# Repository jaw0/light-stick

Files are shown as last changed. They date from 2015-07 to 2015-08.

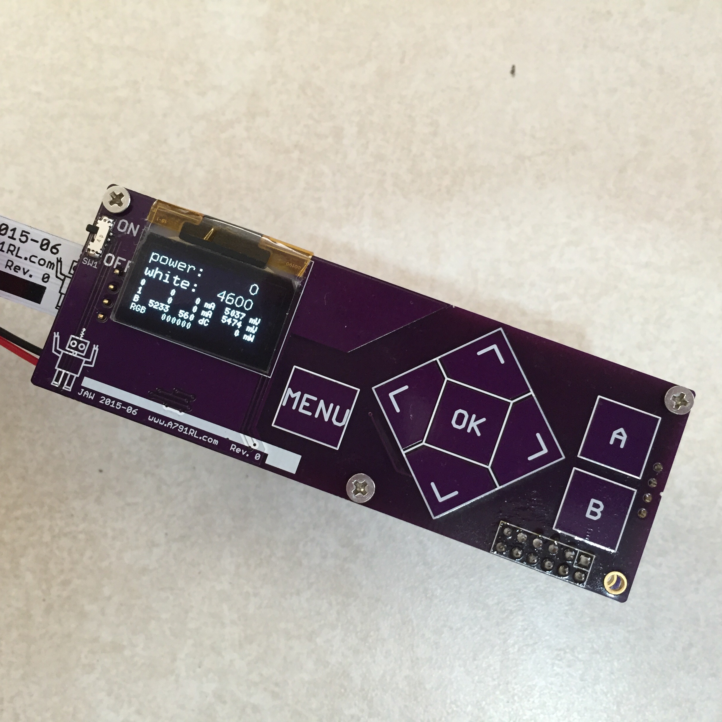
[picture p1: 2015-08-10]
img/userinterface.jpg

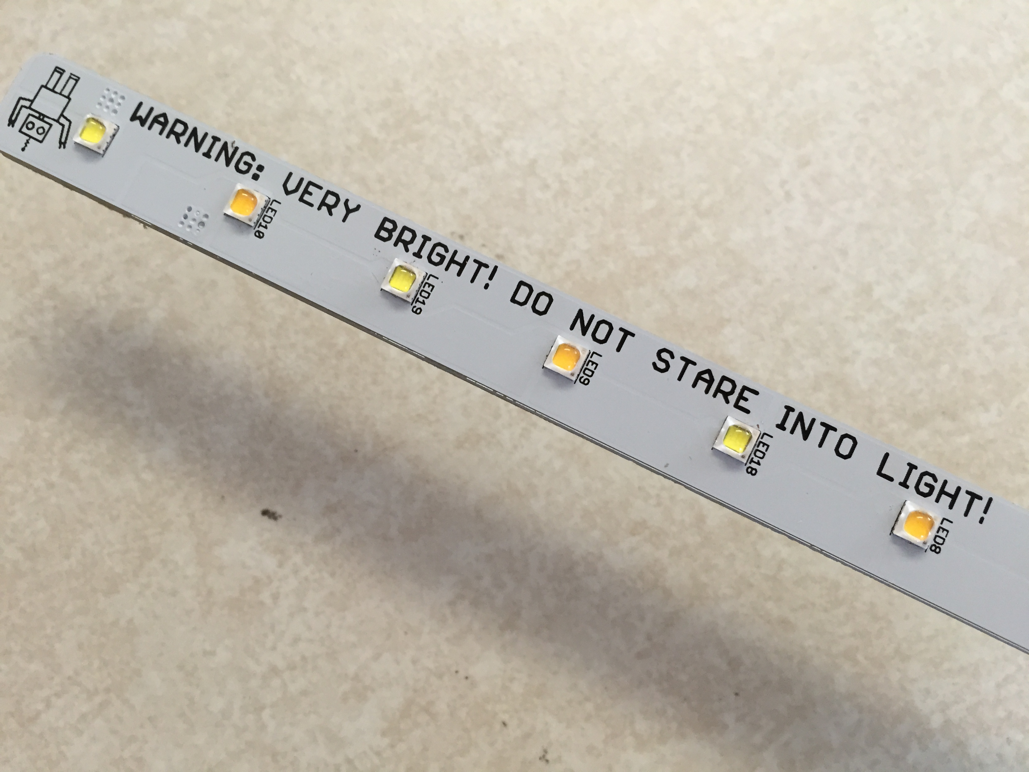
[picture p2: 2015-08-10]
img/leds.jpg

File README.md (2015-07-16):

LED based, battery powered light for photography + videography
modeled after Wescott's "Ice Light"

* aprox 4300 lumens

* 38 Watts

* adjustable power level

* adjustable color temperature: 2700K - 6500K

* consistent + stable output + color even as batteries die

* flicker free

* remembers settings when turned off

* OLED display + touch panel user interface

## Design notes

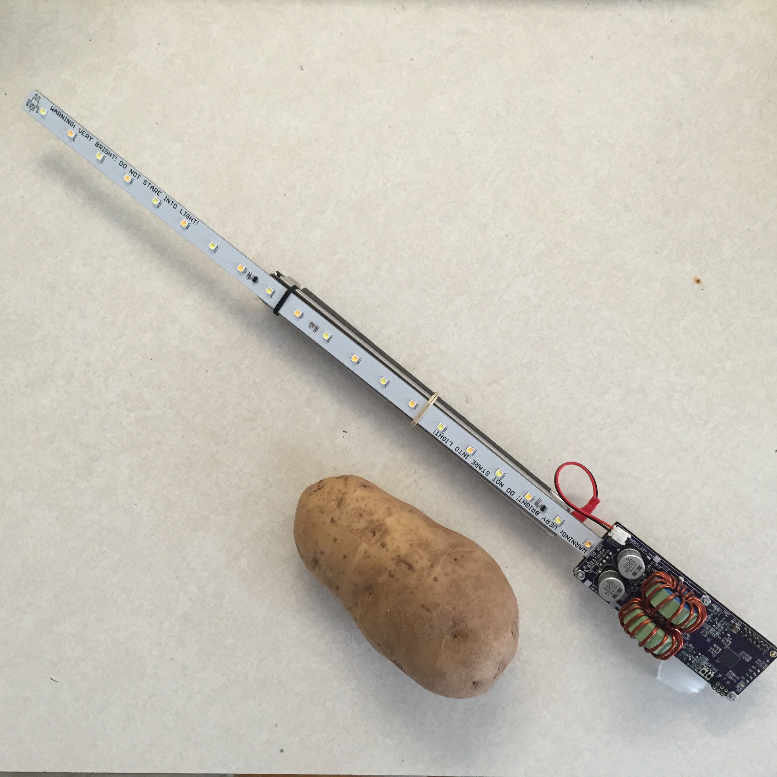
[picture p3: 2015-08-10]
img/potato-for-scale.jpg

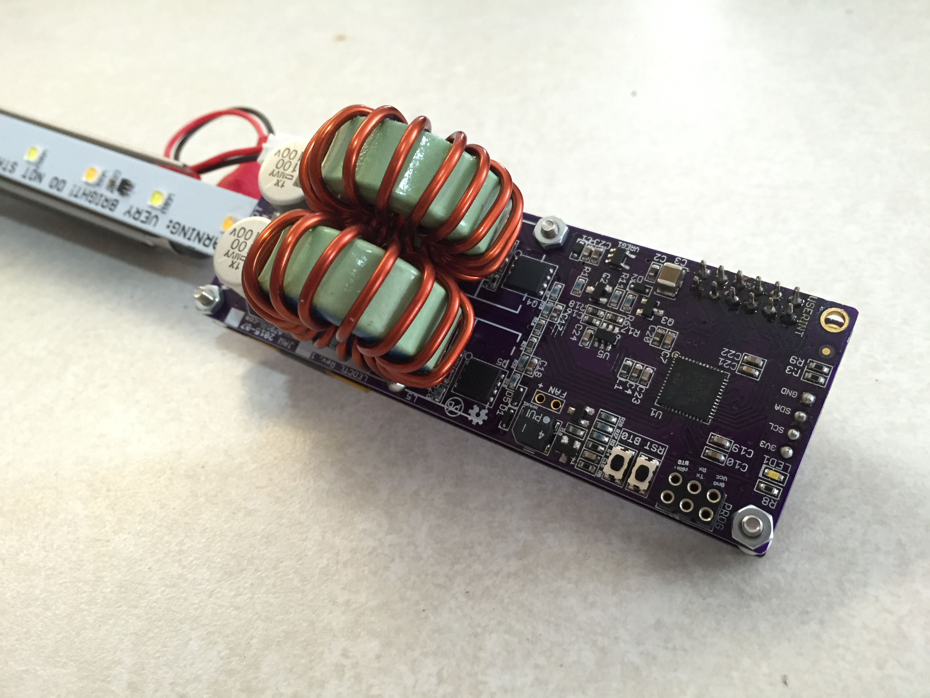
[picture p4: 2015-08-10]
img/mainpcb.jpg

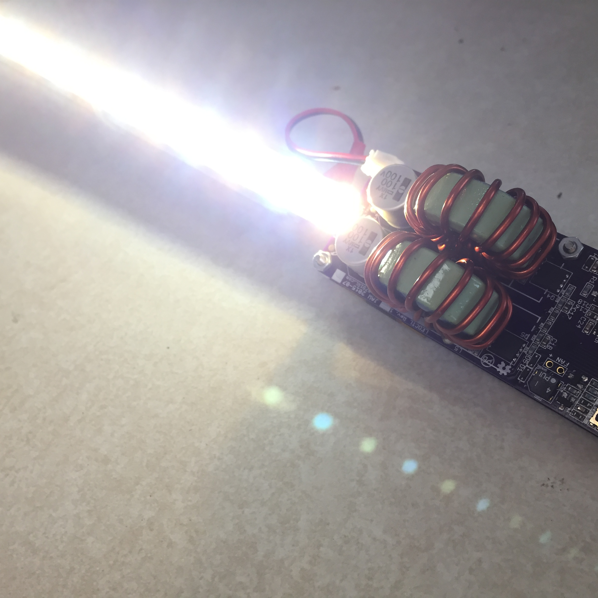
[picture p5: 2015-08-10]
img/lit-up-10watts.jpg

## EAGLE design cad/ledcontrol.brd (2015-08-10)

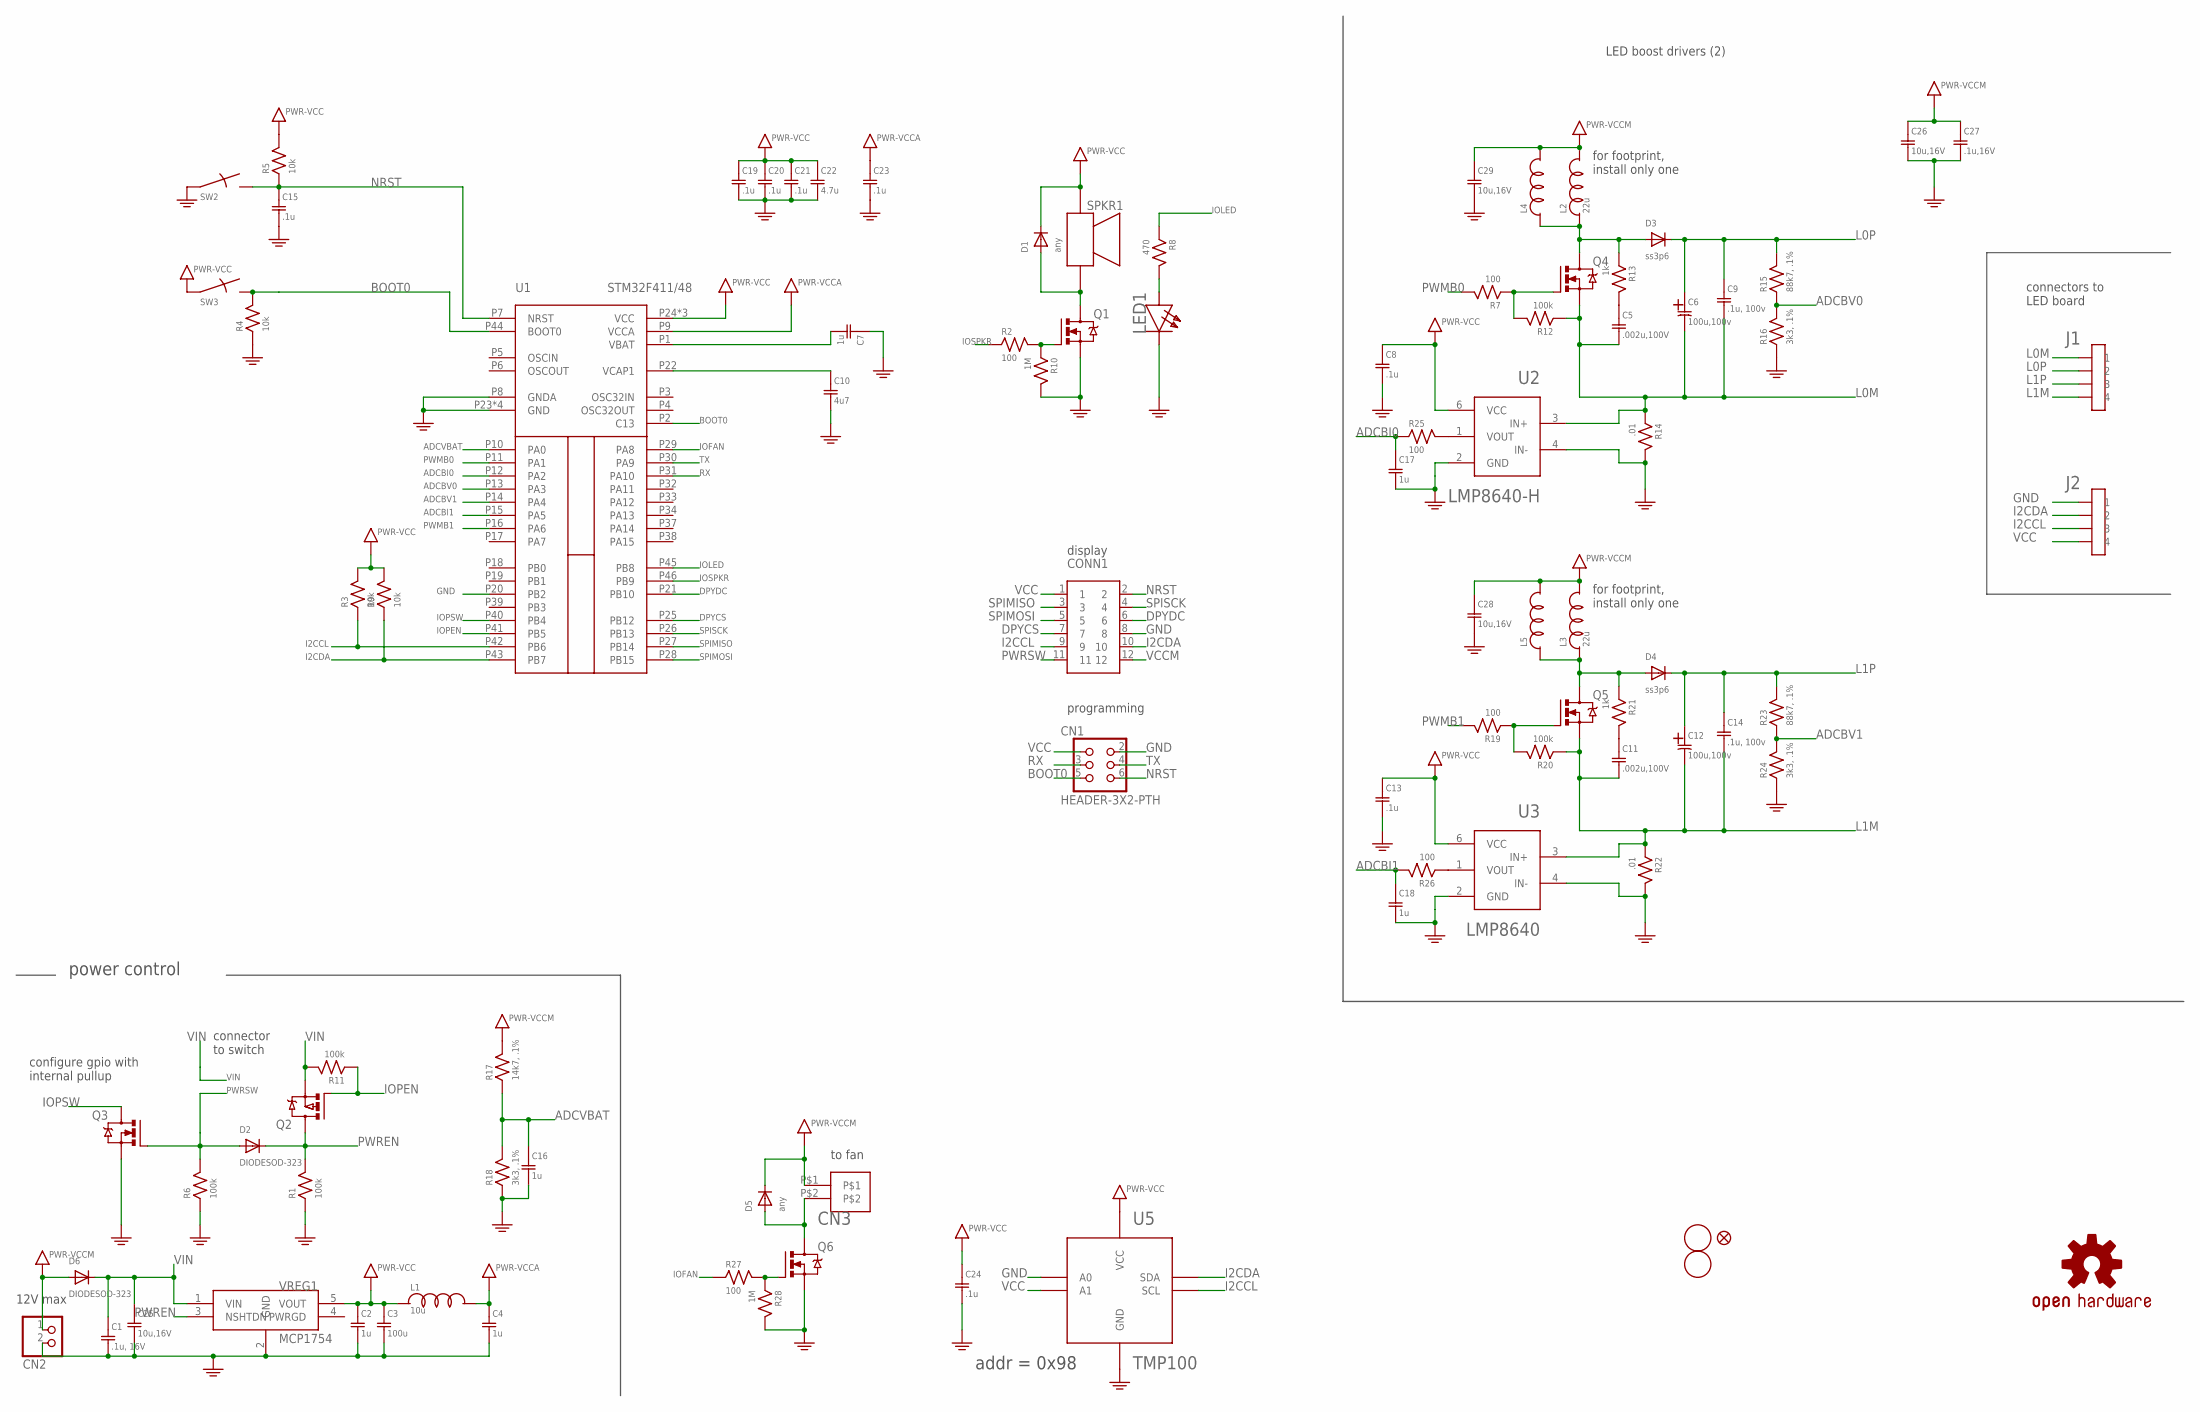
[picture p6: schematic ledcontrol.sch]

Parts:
C1: .1u, 16V; SMD0603
C2, C4, C7, C16, C17, C18: 1u; SMD0603
C3: 100u; SMD1210
C5, C11: .002u,100V; SMD0603
C6, C12: 100u,100v; CAPKE0
C8, C13, C15, C19, C20, C21, C23, C24: .1u; SMD0603
C9, C14: .1u, 100v; SMD0805
C10: 4u7; SMD0603
C22: 4.7u; SMD0603
C25, C26, C28, C29: 10u,16V; SMD0603
C27: .1u,16V; SMD0603
CN1: HEADER-3X2-PTH
CN2: JST_2PIN-THM-RA; JST-PH-2-THM-RA
CN3: HEADER-1X2-THM
CONN1: HEADER-6X2-PTH
D1, D5: any; SOD-323
D2, D6: DIODESOD-323; SOD-323
D3, D4: ss3p6; DO-214AC
FID1: FIDUCIALUFIDUCIAL; MICRO-FIDUCIAL
J1, J2: HEADER-4X1-PTH
L1: 10u; SMD0603
L2, L3: 22u; BOURNS2303
L4, L5: L-SRR1260; SRR1260
LED1: white; SMD0603D
LOGO1: OSHW-LOGOS; OSHW-LOGO-S
Q1, Q6: IRLML6344TRPBF; SOT-23-3
Q2: MOSFET-P; SOT-23-3@1
Q3: MOSFETSOT-23; SOT-23-3
Q4, Q5: AON6246; DFN5X6-8LEP1
R1, R6, R11, R12, R20: 100k; SMD0603
R2, R7, R19, R25, R26, R27: 100; SMD0603
R3, R4, R5, R9: 10k; SMD0603
R8: 470; SMD0603
R10, R28: 1M; SMD0603
R13, R21: 1k; SMD0603
R14, R22: .01; SMD1206
R15, R23: 88k7, .1%; SMD0603
R16, R18, R24: 3k3, .1%; SMD0603
R17: 14k7, .1%; SMD0603
SPKR1: PUI-5040; PUI-0540
SW2, SW3: SWITCHKMR211; KMR211
U1: STM32F411/48; UQPFN48
U2: LMP8640-H; SOT-23-6
U3: LMP8640; SOT-23-6
U5: TMP100; SOT-23-6
U$1, U$2: FIDUCIAL; FIDUCIAL_1MM
VREG1: MCP1754; SOT-23-5

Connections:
ADCBI0: C17.1, R25.1, U1.P12 (PA2)
ADCBI1: C18.1, R26.2, U1.P15 (PA5)
ADCBV0: R15.1, R16.2, U1.P13 (PA3)
ADCBV1: R23.1, R24.2, U1.P14 (PA4)
ADCVBAT: C16.1, R17.1, R18.2, U1.P10 (PA0)
BOOT0: CN1.5, R4.2, SW3.2, SW3.4, U1.P2 (C13), U1.P44 (BOOT0)
DPYCS: CONN1.7, U1.P25 (PB12)
DPYDC: CONN1.6, U1.P21 (PB10)
GND: C1.2, C2.2, C3.2, C4.2, C7.1, C8.2, C10.2, C13.2, C15.2, C16.2, C17.2, C18.2, C19.2, C20.2, C21.2, C22.2, C23.2, C24.2, C25.2, C26.2, C27.2, C28.2, C29.2, CN1.2, CN2.2 (1), CONN1.8, J2.P$1 (1), LED1.C, Q1.2 (S), Q3.2 (S), Q6.2 (S), R1.1, R4.1, R6.1, R10.2, R14.2, R16.1, R18.1, R22.2, R24.1, R28.2, SW2.1, SW2.3, U1.P8 (GNDA), U1.P20 (PB2), U1.P23 (GND), U1.P35 (GND), U1.P47 (GND), U1.PAD (GND), U2.2 (GND), U2.4 (IN-), U3.2 (GND), U3.4 (IN-), U5.2 (GND), U5.5 (A0), VREG1.2 (GND)
I2CCL: CONN1.9, J2.P$3 (3), R3.1, U1.P42 (PB6), U5.1 (SCL)
I2CDA: CONN1.10, J2.P$2 (2), R9.1, U1.P43 (PB7), U5.6 (SDA)
IOFAN: R27.1, U1.P29 (PA8)
IOLED: R8.1, U1.P45 (PB8)
IOPEN: Q2.1 (G), R11.1, U1.P41 (PB5)
IOPSW: Q3.3 (D), U1.P40 (PB4)
IOSPKR: R2.1, U1.P46 (PB9)
L0M: C5.2, C6.N, C9.2, J1.P$1 (1), Q4.P$1 (S), Q4.P$2 (S), Q4.P$3 (S), R12.1, R14.1, U2.3 (IN+)
L0P: C6.P, C9.1, D3.C, J1.P$2 (2), R15.2
L1M: C11.2, C12.N, C14.2, J1.P$4 (4), Q5.P$1 (S), Q5.P$2 (S), Q5.P$3 (S), R20.1, R22.1, U3.3 (IN+)
L1P: C12.P, C14.1, D4.C, J1.P$3 (3), R23.2
unnamed: D3.A, L2.P$1, L4.P$1, Q4.P$5 (D), Q4.P$6 (D), Q4.P$7 (D), Q4.P$8 (D), Q4.P$9 (D), R13.1
unnamed: C5.1, R13.2
unnamed: Q4.P$4 (G), R7.1, R12.2
unnamed: Q1.1 (G), R2.2, R10.1
unnamed: LED1.A, R8.2
unnamed: D4.A, L3.P$1, L5.P$1, Q5.P$5 (D), Q5.P$6 (D), Q5.P$7 (D), Q5.P$8 (D), Q5.P$9 (D), R21.1
unnamed: C11.1, R21.2
unnamed: D1.A, Q1.3 (D), SPKR1.P2
unnamed: Q5.P$4 (G), R19.1, R20.2
unnamed: R25.2, U2.1 (VOUT)
unnamed: R26.1, U3.1 (VOUT)
unnamed: C10.1, U1.P22 (VCAP1)
unnamed: CN3.P$2, D5.A, Q6.3 (D)
unnamed: Q6.1 (G), R27.2, R28.1
unnamed: C7.2, U1.P1 (VBAT)
NRST: C15.1, CN1.6, CONN1.2, R5.1, SW2.2, SW2.4, U1.P7 (NRST)
PWMB0: R7.2, U1.P11 (PA1)
PWMB1: R19.2, U1.P16 (PA6)
PWREN: D2.C, Q2.3 (D), R1.2, VREG1.3 (NSHTDN)
PWRSW: CONN1.11, D2.A, Q3.1 (G), R6.2
RX: CN1.3, U1.P31 (PA10)
SPIMISO: CONN1.3, U1.P27 (PB14)
SPIMOSI: CONN1.5, U1.P28 (PB15)
SPISCK: CONN1.4, U1.P26 (PB13)
TX: CN1.4, U1.P30 (PA9)
VCC: C2.1, C3.1, C8.1, C13.1, C19.1, C20.1, C21.1, C22.1, C24.1, CN1.1, CONN1.1, D1.C, J2.P$4 (4), L1.1, R3.2, R5.2, R9.2, SPKR1.P1, SW3.1, SW3.3, U1.P24 (VCC), U1.P36 (VCC), U1.P48 (VCC), U2.6 (VCC), U3.6 (VCC), U5.3 (A1), U5.4 (VCC), VREG1.5 (VOUT)
VCCA: C4.1, C23.1, L1.2, U1.P9 (VCCA)
VCCM: C26.1, C27.1, C28.1, C29.1, CN2.1 (2), CN3.P$1, CONN1.12, D5.C, D6.A, L2.P$2, L3.P$2, L4.P$2, L5.P$2, R17.2
VIN: C1.1, C25.1, D6.C, Q2.2 (S), R11.2, VREG1.1 (VIN)

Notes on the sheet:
configure gpio with internal pullup
power control
LED boost drivers (2)
connector to switch
12V max
display
programming
connectors to LED board
to fan
addr = 0x98
for footprint, install only one

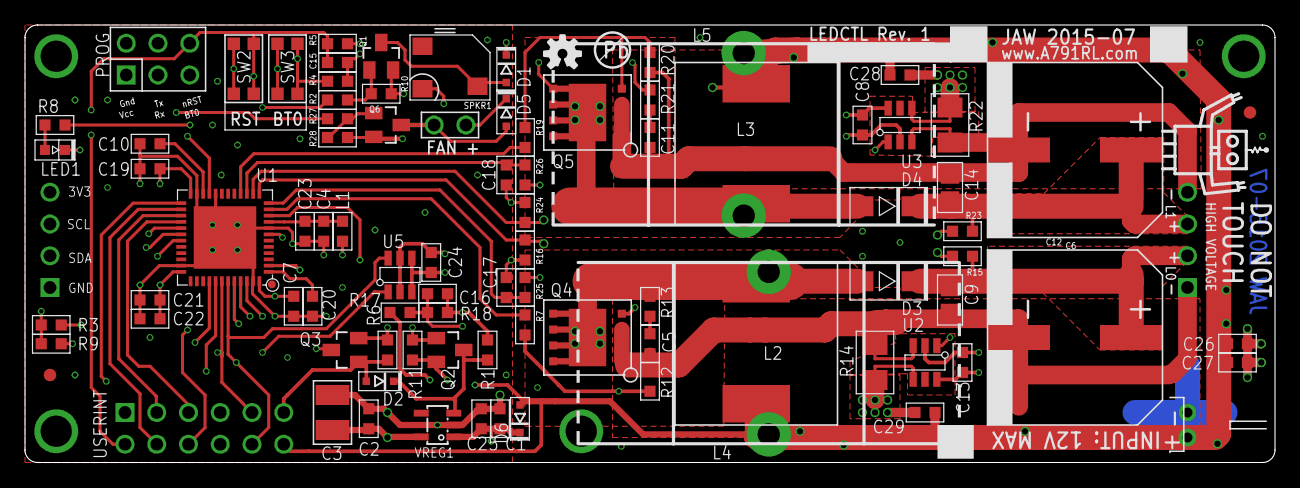
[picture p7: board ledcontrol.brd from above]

Board: 4 copper layers, 100.0 x 35.0 mm, 93 parts (1 on the bottom side), 49 nets.

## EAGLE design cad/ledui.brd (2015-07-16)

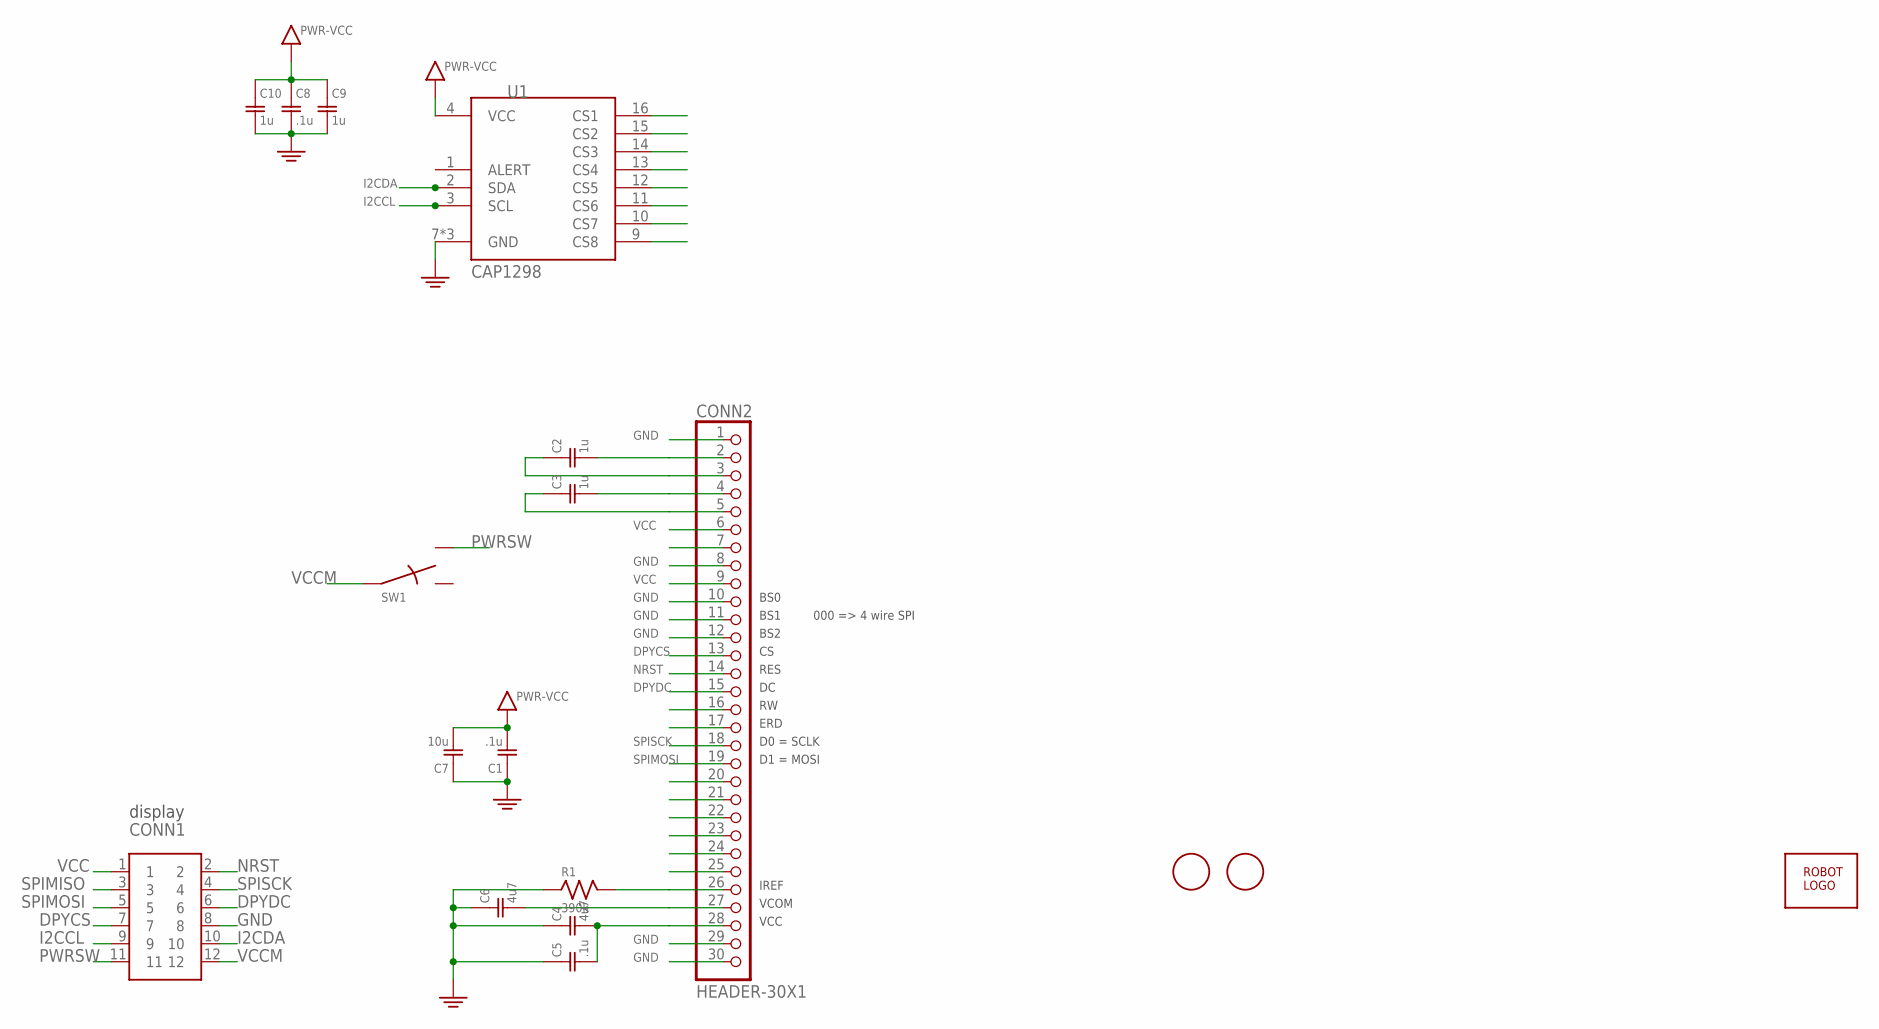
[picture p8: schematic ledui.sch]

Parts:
C1, C5, C8: .1u; SMD0603
C2, C3, C9, C10: 1u; SMD0603
C4, C6: 4u7; SMD0603
C7: 10u; SMD0603
CONN1: HEADER-6X2-PTH
CONN2: HEADER-30X1; HEADER-30X1-SMD7
R1: 390k; SMD0603
SW1: SWITCH-SPDT; ALPS-SSAJ120100
U1: CAP1298; QFN16EP
U$1, U$2: FIDUCIAL; FIDUCIAL_1MM
U$3: ROBOTMAN-LOGO

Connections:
CS1: U1.16 (CS1)
CS2: U1.15 (CS2)
CS3: U1.14 (CS3)
CS4: U1.13 (CS4)
CS5: U1.12 (CS5)
CS6: U1.11 (CS6)
CS7: U1.10 (CS7)
CS8: U1.9 (CS8)
DPYCS: CONN1.7, CONN2.13
DPYDC: CONN1.6, CONN2.15
GND: C1.1, C4.1, C5.1, C6.1, C7.1, C8.2, C9.2, C10.2, CONN1.8, CONN2.1, CONN2.8, CONN2.10, CONN2.11, CONN2.12, CONN2.29, CONN2.30, R1.1, U1.7 (GND), U1.8 (GND), U1.P$1 (GND)
I2CCL: CONN1.9, U1.3 (SCL)
I2CDA: CONN1.10, U1.2 (SDA)
unnamed: C3.2, CONN2.4
unnamed: C2.1, CONN2.3
unnamed: C3.1, CONN2.5
unnamed: C2.2, CONN2.2
unnamed: CONN2.26, R1.2
unnamed: C6.2, CONN2.27
unnamed: C4.2, C5.2, CONN2.28
NRST: CONN1.2, CONN2.14
PWRSW: CONN1.11, SW1.2
SPIMISO: CONN1.3
SPIMOSI: CONN1.5, CONN2.19
SPISCK: CONN1.4, CONN2.18
VCC: C1.2, C7.2, C8.1, C9.1, C10.1, CONN1.1, CONN2.6, CONN2.9, U1.4 (VCC)
VCCM: CONN1.12, SW1.C

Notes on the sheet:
display
BS0
BS1
BS2
000 => 4 wire SPI
RES
ERD
D0 = SCLK
D1 = MOSI
IREF
VCOM
VCC

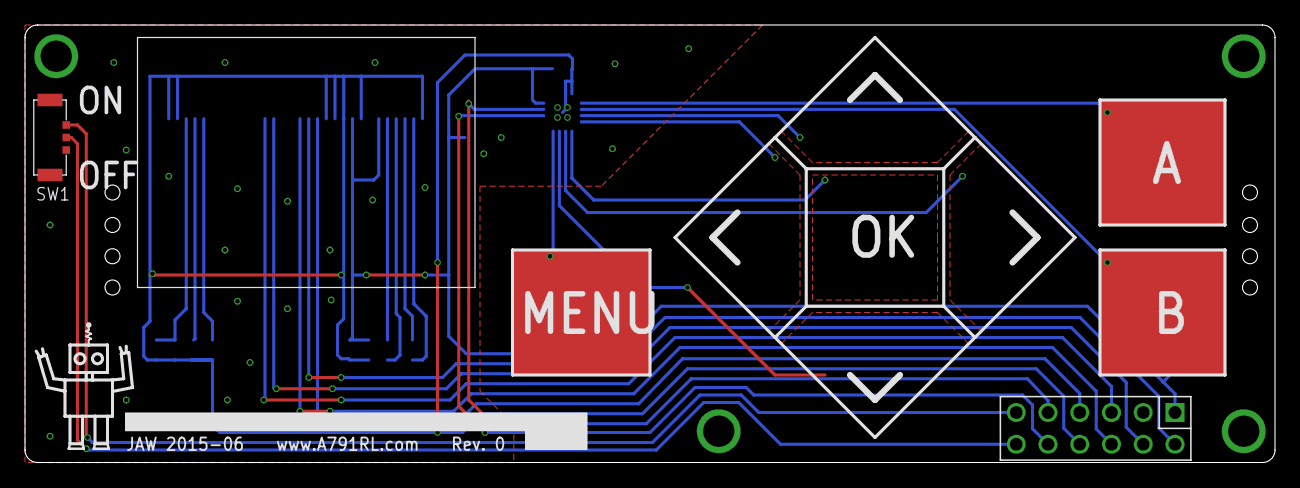
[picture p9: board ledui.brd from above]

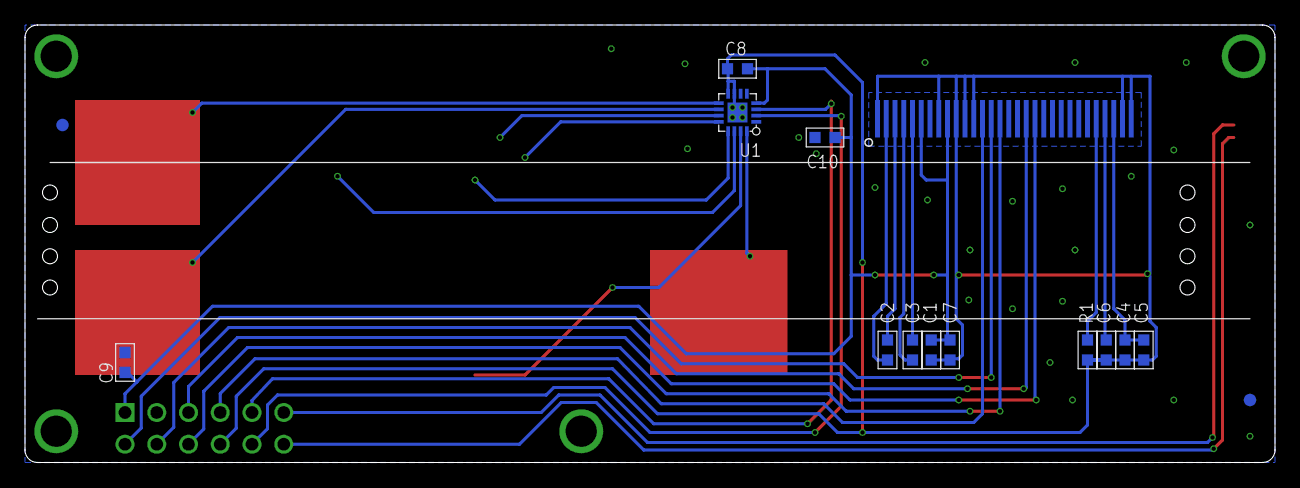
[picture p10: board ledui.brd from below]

Board: 2 copper layers, 100.0 x 35.0 mm, 18 parts (15 on the bottom side), 18 nets.

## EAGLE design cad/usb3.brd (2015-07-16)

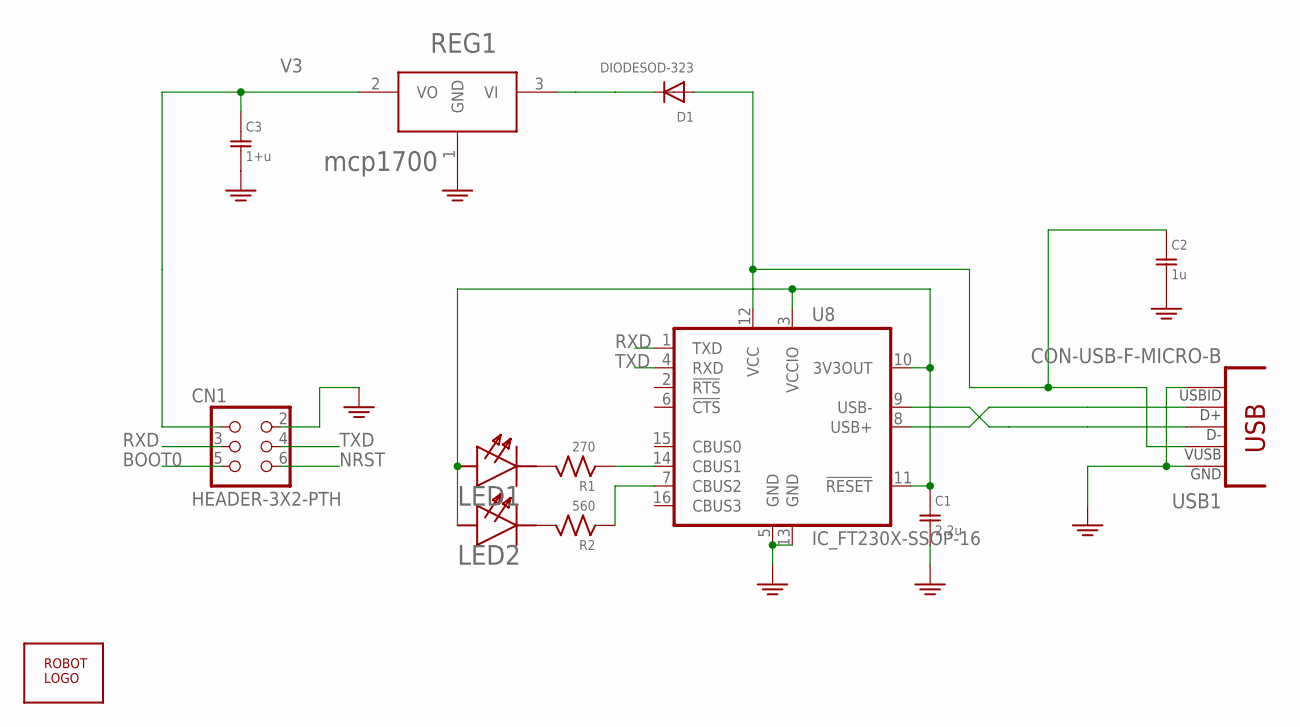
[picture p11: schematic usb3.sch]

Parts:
C1: 2.2u; SMD0603
C2: 1u; SMD0603
C3: 1+u; SMD0603
CN1: HEADER-3X2-PTH
D1: DIODESOD-323; SOD-323
LED1: GREEN; SMD0603D
LED2: ORANGE; SMD0603D
R1: 270; SMD0603
R2: 560; SMD0603
REG1: mcp1700; SOT-23-3
U8: IC_FT230X-SSOP-16; SSOP-16-FTDI
U$1: ROBOTMAN-LOGO
USB1: CON-USB-F-MICRO-B; CONN_USB_MICRO-B

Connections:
BOOT0: CN1.5
GND: C1.2, C2.2, C3.2, CN1.2, REG1.1 (GND), U8.5 (GND), U8.13 (GND), USB1.P4 (USBID), USB1.P5 (GND)
unnamed: D1.C, REG1.3 (VI)
unnamed: U8.8 (USB+), USB1.P3 (D+)
unnamed: U8.9 (USB-), USB1.P2 (D-)
unnamed: LED1.C, R1.2
unnamed: LED2.C, R2.2
unnamed: R1.1, U8.14 (CBUS1)
unnamed: R2.1, U8.7 (CBUS2)
NRST: CN1.6
RXD: CN1.3, U8.1 (TXD)
TXD: CN1.4, U8.4 (RXD)
USB3V3: C1.1, LED1.A, LED2.A, U8.3 (VCCIO), U8.10 (3V3OUT), U8.11 (!RESET)
V3: C3.1, CN1.1, REG1.2 (VO)
VBUS: C2.1, D1.A, U8.12 (VCC), USB1.P1 (VUSB)

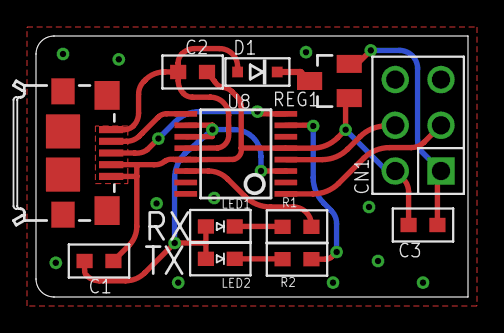
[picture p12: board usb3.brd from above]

Board: 2 copper layers, 24.0 x 14.5 mm, 13 parts (1 on the bottom side), 13 nets.

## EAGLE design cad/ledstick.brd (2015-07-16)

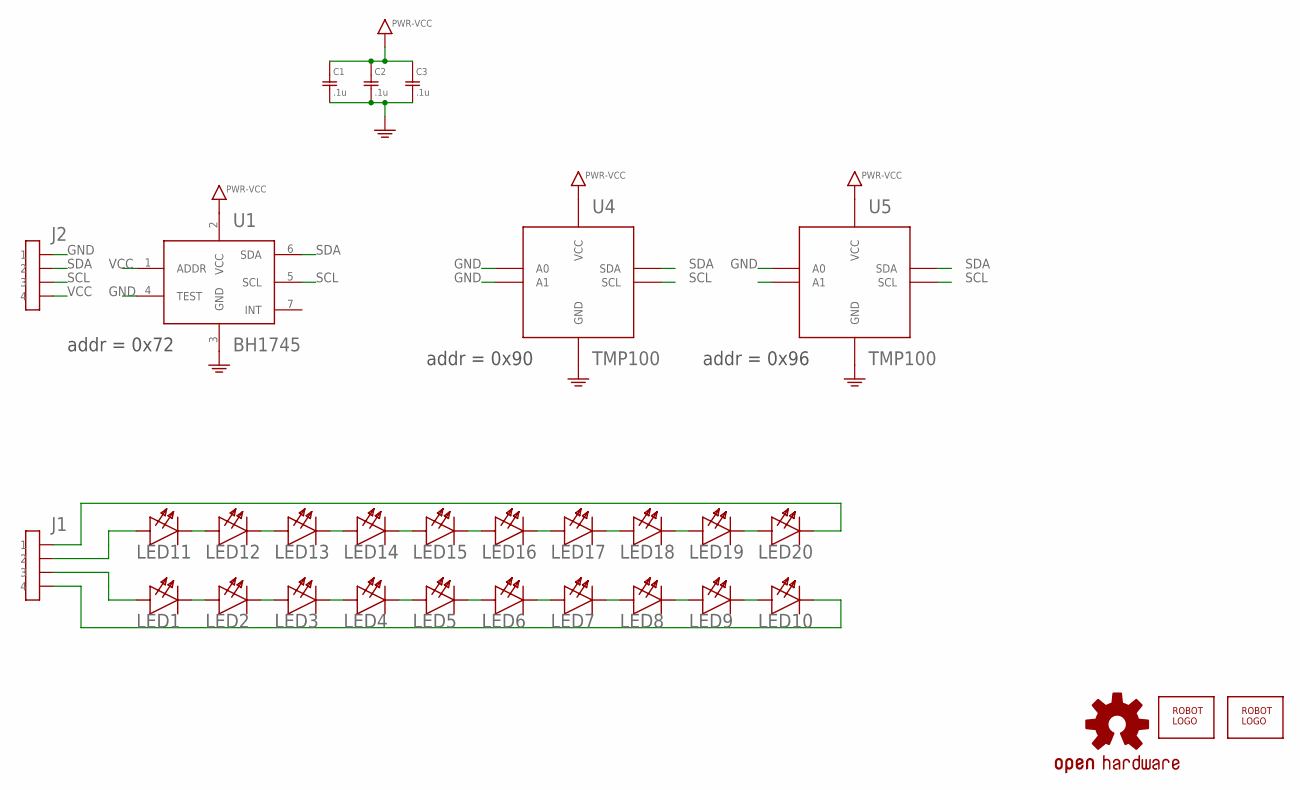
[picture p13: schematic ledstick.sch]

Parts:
C1, C2, C3: .1u; SMD0603
J1, J2: HEADER-4X1-PTH
LED1, LED2, LED3, LED4, LED5, LED6, LED7, LED8, LED9, LED10: W; LED4-4P1A
LED11, LED12, LED13, LED14, LED15, LED16, LED17, LED18, LED19, LED20: C; LED4-4P1A
LOGO1: OSHW-LOGOM; OSHW-LOGO-M
U1: BH1745; WSON8
U4, U5: TMP100; SOT-23-6
U$1, U$2: ROBOTMAN-LOGO

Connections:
GND: C1.2, C2.2, C3.2, J2.P$1 (1), U1.3 (GND), U1.4 (TEST), U4.2 (GND), U4.3 (A1), U4.5 (A0), U5.2 (GND), U5.5 (A0)
unnamed: LED1.C, LED2.A, LED2.AP (A)
unnamed: LED2.C, LED3.A, LED3.AP (A)
unnamed: LED3.C, LED4.A, LED4.AP (A)
unnamed: LED4.C, LED5.A, LED5.AP (A)
unnamed: LED5.C, LED6.A, LED6.AP (A)
unnamed: LED6.C, LED7.A, LED7.AP (A)
unnamed: LED7.C, LED8.A, LED8.AP (A)
unnamed: LED8.C, LED9.A, LED9.AP (A)
unnamed: LED9.C, LED10.A, LED10.AP (A)
unnamed: LED11.C, LED12.A, LED12.AP (A)
unnamed: LED12.C, LED13.A, LED13.AP (A)
unnamed: LED13.C, LED14.A, LED14.AP (A)
unnamed: LED14.C, LED15.A, LED15.AP (A)
unnamed: LED15.C, LED16.A, LED16.AP (A)
unnamed: LED16.C, LED17.A, LED17.AP (A)
unnamed: LED17.C, LED18.A, LED18.AP (A)
unnamed: LED18.C, LED19.A, LED19.AP (A)
unnamed: LED19.C, LED20.A, LED20.AP (A)
unnamed: J1.P$2 (2), LED11.A, LED11.AP (A)
unnamed: J1.P$3 (3), LED1.A, LED1.AP (A)
unnamed: J1.P$1 (1), LED20.C
unnamed: J1.P$4 (4), LED10.C
SCL: J2.P$3 (3), U1.5 (SCL), U4.1 (SCL), U5.1 (SCL)
SDA: J2.P$2 (2), U1.6 (SDA), U4.6 (SDA), U5.6 (SDA)
VCC: C1.1, C2.1, C3.1, J2.P$4 (4), U1.1 (ADDR), U1.2 (VCC), U4.4 (VCC), U5.4 (VCC)

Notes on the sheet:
addr = 0x90
addr = 0x96
addr = 0x72

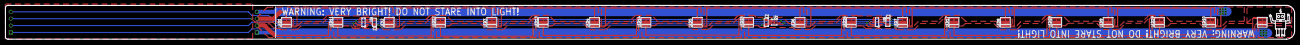
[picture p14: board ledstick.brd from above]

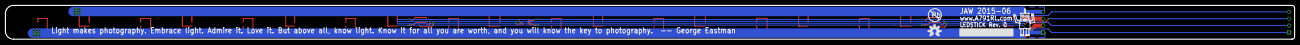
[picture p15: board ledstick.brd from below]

Board: 2 copper layers, 477.0 x 12.5 mm, 31 parts (2 on the bottom side), 26 nets.

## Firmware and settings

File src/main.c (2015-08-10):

/*
  Copyright (c) 2015
  Author: Jeff Weisberg <jaw @ tcp4me.com>
  Created: 2015-Apr-02 21:37 (EDT)
  Function: 

*/

#include <conf.h>
#include <proc.h>
#include <gpio.h>
#include <pwm.h>
#include <adc.h>
#include <spi.h>
#include <i2c.h>
#include <ioctl.h>
#include <error.h>
#include <stm32.h>
#include <userint.h>

#include "util.h"


#define FLASHSTART	0x08000000
extern const u_char* _etext;
extern int blinky_override;


extern void blinky(void);

// first look on the card, then flash
// NB: if we check the flash first, a bad config could brick the system
#define RUN_SCRIPT(file)        (run_script("fl0:" file))

DEFVAR(int, lights_autostart, 1, UV_TYPE_UL | UV_TYPE_CONFIG, "should we start up the lighting system")


DEFUN(save, "save all config data")
{
    save_config("fl0:config.rc");
    return 0;
}

unsigned int
random(void){
    static unsigned int x;
    unsigned int y;

    y = RTC->SSR ^ RTC->TR;
    y ^= RTC->DR;
    y ^= SysTick->VAL;

    x = (x<<7) | (x>>25);
    x ^= y;
    return x ^ lrand48();
}

DEFUN(set_autostart, 0)
{
    if( argc < 2 ) return 0;
    lights_autostart = atoi( argv[1]);
    save_config("fl0:config.rc");
    reboot();
    return 0;
}


#if defined(USE_SSD1306)
#  define dpy_puts	ssd13060_puts
#elif defined(USE_SSD1331)
#  define dpy_puts	ssd13310_puts
#elif defined(USE_EPAPER)
#  define dpy_puts	epaper0_puts
#endif


// on panic: beep, flash, and display message
// NB: system will also output to the console
void
onpanic(const char *msg){
    int i;

    blinky_override = 1;
    set_led_white( 0xFF );
    beep_set(200, 127);

    lights_safe();

    splproc();
    currproc = 0;

    dpy_puts("\e[J\e[16m*** PANIC ***\r\n\e[15m");
    if( msg ){
        dpy_puts(msg);
        dpy_puts("\r\n");
    }
    splhigh();

    while(1){
        set_led_white( 0xFF );
        beep_set(150, 127);
        for(i=0; i<5000000; i++){ asm("nop"); }
        set_led_white( 0x1F );
        beep_set(250, 127);
        for(i=0; i<5000000; i++){ asm("nop"); }
    }
}

//################################################################

// put all peripherals in their lowest power mode
// put the processor into "standby" mode

void
shutdown(void){
    kprintf("powering down\n");
    save_config("fl0:config.rc");

    board_disable();
    power_down();
}


DEFUN(shutdown, "shut down system")
DEFALIAS(shutdown, poweroff)
DEFALIAS(shutdown, halt)
{
    shutdown();
    return 0;
}

//################################################################

void
main(void){

    board_init();
    set_led_white( 0xFF );	// flash LED
    RUN_SCRIPT("config.rc");

    play(6, "b4>f4b4");
    RUN_SCRIPT("startup.rc");

    set_led_white( 0 );
    start_proc(512, blinky, "blinky");

    if( lights_autostart )
        lights_start();

    printf("\n");

    // return to serial shell
}

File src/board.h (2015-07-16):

/*
  Copyright (c) 2015
  Author: Jeff Weisberg <jaw @ tcp4me.com>
  Created: 2015-Apr-02 21:37 (EDT)
  Function: 

*/

#define I2CUNIT			0

#define HWCF_GPIO_BUTTON         GPIO_C13
#define HWCF_GPIO_DPY_CD         GPIO_B10
#define HWCF_GPIO_DPY_CS         GPIO_B12
#define HWCF_GPIO_LED_WHITE      GPIO_B8
#define HWCF_GPIO_AUDIO          GPIO_B9
#define HWCF_GPIO_LEDS0	 	 GPIO_A1
#define HWCF_GPIO_LEDS1	 	 GPIO_A6
#define HWCF_GPIO_FAN		 GPIO_A8
#define HWCF_GPIO_PSWITCH	 GPIO_B4
#define HWCF_GPIO_POWEREN	 GPIO_B5

#define HWCF_TIMER_LED_WHITE     TIMER_4_3
#define HWCF_TIMER_AUDIO         TIMER_4_4
#define HWCF_TIMER_LEDS0	 TIMER_2_2
#define HWCF_TIMER_LEDS1	 TIMER_3_1
#define HWCF_TIMER_FAN		 TIMER_1_1

#define HWCF_ADC_BATV		ADC_1_0
#define HWCF_ADC_L0I		ADC_1_2
#define HWCF_ADC_L0V		ADC_1_3
#define HWCF_ADC_L1I		ADC_1_5
#define HWCF_ADC_L1V		ADC_1_4

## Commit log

2015-07-17 more power
    [ledcontrol.brd, ledcontrol.sch]
2015-08-10 fan, clean

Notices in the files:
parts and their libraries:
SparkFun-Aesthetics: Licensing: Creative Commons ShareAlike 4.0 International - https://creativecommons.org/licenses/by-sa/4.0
